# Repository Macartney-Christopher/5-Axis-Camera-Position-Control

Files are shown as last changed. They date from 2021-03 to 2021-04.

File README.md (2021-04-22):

# 5-Axis-Camera-Position-Control
  The "Tasmanian Devil" is a 5-axis camera position control system to get all the video shots you could dream of. The design is an extension of [isaac879](https://github.com/isaac879/Pan-Tilt-Mount)'s camera rig which allows the use of three axes, and shutter control. Using Isaac879's available pinouts and step files, their design was modified to account for focus and zoom, or dynamic lighting control.
  Go see the final product in action on YouTube [here](https://www.youtube.com/watch?v=kPsWlgf-iiQ)! 
  To understand the modifications made it is strongly suggested to look at [isaac879](https://github.com/isaac879/Pan-Tilt-Mount)'s original work on this project.

## Table of Contents
### 1. [Mechanical Design](Mechanical.md)
### 2. [Hardware Design](Hardware.md)
### 3. [Software Design](Software.md)

## Setup
1. Plug the power cable to an outlet
2. Plug the Xbox controller and the USB cable to your computer
3. Download the repository and extract the folder [Tasmanian_Launch](Tasmanian_Launch).
4. Update [serial_port.txt](Tasmanian_Launch/serial_port.txt) in the folder with the port that the Nano is connected to. Go to Device Manager>Ports to find the port number (ex: COM4).
5. Double-click on [Tasmanian_Launch.bat](Tasmanian_Launch/Tasmanian_Launch.bat)
6. Enjoy!

## Do It Yourself
### Build
1. Upload the Arduino code to the Nano 33 IoT
3. Assemble the 3D prints
4. Set up the wiring
5. Open the and compile the Bluetooth code on C++ compiler

#### With Gaming Controller
&nbsp;&nbsp;&nbsp;Follow the "Setup" protocol

#### Without Gaming Controller
1. Compile the Arduino code [here](FlashStorage_PanTiltMount/FlashStorage_PanTiltMount.ino) 
3. Ensure all cables are connected
4. Compile and execute
5. Operate in Arduino IDE using [these commands](FlashStorage_PanTiltMount/5-Axis_Position_Control_Commands.pdf)

## Credits
  The mechanical, hardware and software design is an adapted version of [isaac879](https://github.com/isaac879/Pan-Tilt-Mount)'s project. Isaac879 did a tremendous job with every aspect of the project and shows great skill in his other project as well. [Isaac879's video](https://www.youtube.com/watch?v=1FfB7cLkUyQ) is very well structured and edited.
## License
[Project license](LICENSE).

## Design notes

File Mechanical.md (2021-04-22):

# Mechanical


## Camera Mount Adaptability
  - Design 1: Extendable Camera Mount
    - Motive: Possibility that a camera will not fit
      - Allows a snug fit for any camera
      -	Reduces possibility for camera to rotate on center screw
      -	Required additional sliding mechanisms
      -	Involved too little rigidity in the system
  - Design 2: Freedom of Screw Position & Larger Mount
    - Motive: Not enough options for camera position
      -	Allows fit for all current and future DSLRs
      -	Allows for lateral and longitudinal positioning of camera
      -	Allows for optimal position of center of mass
      -	Possibility of camera rotation (mitigated by tightness 

    #### Design 2 outweighed Design 1
 

## Slider Mount Tightening
  - Design 1: Spring Loaded Wheel Shaft (4 wheels total)
    - Motive: Consistent Fitment to Rail 
      - Allows for simple setup
      - Requires strong springs in compression
      - Not mechanically reliable
  - Design 2: Eccentric Screw (3 wheels total)
    - Motive: More efficient design solution
      - Uses less wheels
      -	Allows for higher mechanical reliability
      -	Allows for desired tightness using tools
      -	3D printable

    #### Design 2 outweighed Design 1
    

## Additional Stepper Motors - Focus & Zoom Control
  - Design 1: Motors attached on the camera mount and adjustable
    - Motive: Fixed on the path of the camera
      -	Allows adjustability of both axes (focus & zoom)
      -	Proximity to lens
      -	Collides with the board and wiring in all optimal camera shots
  - Design 2: Motors attached to the external flash unit of the camera
    - Motive: Fixed on the path of the camera
      -	Allows adjustability of both axes (focus & zoom)
      -	Proximity to lens
      -	Only collides with board if camera is upside-down (unlikely)
      -	Gravity helps prevent any skipping of the gears because they are above the lens

	  #### Design 2 outweighed Design 1
	  

## Dynamic Lighting
&nbsp;&nbsp;&nbsp;To control the lights alongside the entire "Tasmanian Devil" the design must be compatible with the current light and tripod design. The following design allows for the rig to be easily set on the tripod and controlled from a distance.



## 3D Printing Material
&nbsp;&nbsp;&nbsp;The entire 5-axis camera rig is made of PLA, a relatively strong plastic and easy to work with. Two axes work with gears to increase ratio and precision. The contact from the gears could lead to increased vibrations and inconsistent filming. When printing one of the gears twice, once in semi-flexible and another flexible, there was no significant change to the recording. Moreover, softer teeth could increase the chances of gears skipping which would create shaking in the video at higher speeds. Gears as shown below:<br/>


## Assembling In SolidWorks
### Assembly
&nbsp;&nbsp;&nbsp;When assembling mechanical parts it is to your advantage to include screws, nuts, and other typically ignored components. All CAD files the nuts, screws, and bearings can be found on McMaster-Carr's website with many options for thread, pitch, head, etc. Ignoring to include the screws can lead to possible collisions with parts or even worse, a camera.
For a project like this, it may be advantageous to have a second assembly in which you can include the components to be printed. Often, when printing, offsets and chamfers are required depending on the printer's quality. A second assembly helps visualize the offsets and where you might be missing some.

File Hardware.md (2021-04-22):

# Hardware

&nbsp;&nbsp;&nbsp;The final objective for the camera is to control it via Bluetooth with the given code using the custom PCB. Keep in mind that this report is from a maker who didn't know what a stepper motor was before starting the project.

## CNC Shield: Driving Steppers Directly

&nbsp;&nbsp;&nbsp;With the mechanical parts fully assembled, the camera system needed to be tested. Driving the steppers directly using a CNC Shield through Arduino mitigates any issues that could arise from code and wiring. [Find code here](Iteration2-Code/CNC_Shield_Direct_Drive.ino) .

## CNC Shield: Driving Steppers with Universal G-Code Sender (UGS)
Use Universal G-Code Sender with the CNC Shield to rapidly and realistically simulate the controls of the steppers. 
1. Upload Grbl source code to the Arduino Uno [here on Github](https://github.com/grbl/grbl/blob/master/grbl/examples/grblUpload/grblUpload.ino).
2. Download Universal G-Code Sender and connect your Arduino Uno.
3. Setup stepper motors and drivers to CNC shield.
4. Press connect on the top corner and ensure the Arduino Uno is connected.
5. You're done!
 
#### Problem 
&nbsp;&nbsp;&nbsp;Using UGS for the camera position control is not ideal because entering the G commands manually is tedious. The issue is that the three core motors don't move the body in cartesian axes. Two motors rotate the body around its center and one moves along the x-axis. Moreover, the two motors also have a gear ratio which don't represent the rotation of the body 1:1 with the motors. 

#### Solution
1. Draw what the motors would do in cartesian coordinates and convert to G commands.
	This is an interesting idea because the user could visually see the sequence of motor actuation. The biggest issue is being able to constantly convert to cartesian coordinates as the user draws on two of three axes. 
2. Write code to enter the desired angles of the camera and output the G commands.
	This idea is feasible and both ends of the black box make sense for the user. [See C# code here](Iteration2-Code/GCode_Maker.cs).

&nbsp;&nbsp;&nbsp;The C# program asks for the angle of tilting and panning, and the distance of slider travel. It gives in return two G commands, the first to set the initial position and the second to execute the desired move.
[Watch an example video on Youtube](https://youtu.be/lNg3zl9IBe4).

## Stepper Motor Driver Setup
&nbsp;&nbsp;&nbsp;When installing new drivers on the board make sure that the current limiting is set correctly using the potentiometer. For reference, Current Limit = VRef x 2.
Example: The A4988 stepper driver has a current limit of 2 A, which realistically is a bit less unless the cooling on the IC (integrated circuit) is 100% efficient. Based on the above equation that means the VRef is approximately 0.9 A. To ensure your chip doesn't burn out it is highly suggested to slightly reduce your VRef and add a heat sink to the driver. 
To test if your driver won't burn out turn on your system with your finger on the heat sink, if it gets too hot then immediately turn off your system and troubleshoot.
- Ensure that a motor is connected to draw power
- Double check your current limit and the VRef on the potentiometer
- Test your driver on a working system to check its functionality

## Troubleshoot: Why is my stepper motor not working?

- Is the motor is connected?
- Is the power cable connected and turned on?
- Is the motor receiving enough power? Check with a multimeter
- Is the header for the motor receiving data from the board? Check connections with a multimeter
- Is the motor broken? Plug it into a working system to check its functionality

## Using a Custom PCB
&nbsp;&nbsp;&nbsp;Isaac879 includes the files and the component list to build the PCB in his repository. After soldering the components to the board we can begin testing.
*Note: The final objective is to have five total stepper motors, two more than what the PCB accounts for.*

##### Soldering
&nbsp;&nbsp;&nbsp;The only challenge is keeping the headers in the upright position while soldering on the opposite side. Additionally, this project upgrade counts 3x hall sensors wired to headers, 8x 7-10cm F-F wires, and 2x 7-10cm F-F split wires.

### Nano Compatibility
#### Using an Arduino Nano 
&nbsp;&nbsp;&nbsp;Isaac879 uses almost the entire static and dynamic memory available on an Arduino Nano to complete his project. The PCB worked when adding the Nano to the PCB and uploading isaac879's original code.

##### Problem
&nbsp;&nbsp;&nbsp;Initializing the two additional steppers with AccelStepper quickly takes up memory in the Nano. The code takes up 107% capacity only with initialization. Removing functions that are not critical, such as all that operate the camera shutter, is still not enough. An alternative board is necessary.

##### Solution
&nbsp;&nbsp;&nbsp;The Arduino Nano 33 BLE solves the memory issue. Moreover, the board has CPU Flash Memory which replaces the EEPROM.

#### Using an Arduino Nano 33 BLE
&nbsp;&nbsp;&nbsp;With the Arduino Nano 33 BLE there's plenty of memory to initialize all five stepper motors. The integrated Bluetooth on the Nano 33 BLE makes the Bluetooth header on the PCB available.

##### Problem
&nbsp;&nbsp;&nbsp; An architecture error comes up when changing the EEPROM to FlashStorage:

The architecture of the CPU is not compatible with the FlashStorage library. The workarounds with the same board are complex and require extensive knowledge of CPU architecture.

##### Solution
&nbsp;&nbsp;&nbsp;Finally, the Arduino Nano 33 IoT doesn't present any compilation issues and worked great.

#### Using an Arduino Nano 33 IoT
&nbsp;&nbsp;&nbsp;With the Arduino Nano 33 IoT, everything compiles perfectly. There's enough memory and the correct architecture for the FlashStorage library.

### Finding PCB Pinouts
&nbsp;&nbsp;&nbsp;Adding two more steppers is critical for the project. There are eight free pins on the PCB that can be used for digital signals: D0 (RX), D1 (TX), D2, D13, A1, A2, A6, and A7. Pins 0 and 1, and pin 2 on H1 belong to the camera trigger and a hall sensor respectively. The camera trigger is not necessary for this project, the fourth hall sensor does not add value to this project.
Thankfully the 28BYJ-48 stepper motors and their respective ULN2003 drivers only require four digital pins. The eight pins are perfect for the two small stepper motors.

### Modifying the PCB
&nbsp;&nbsp;&nbsp;*Note: To implement the two additional steppers the camera shutter trigger function must be sacrificed to use its digital pinout.*<br/>
&nbsp;&nbsp;&nbsp;***Suggestion: To not lose the camera trigger function and make the setup cleaner it is suggested to improve on the PCB design and simply order it with the correct modifications as explained below.***

&nbsp;&nbsp;&nbsp;To begin, R1 and R5 must be shorted because their corresponding pins D0 (RX) and A1 pins are not being used for what the PCB intended. Ensure that the resistor is not part of the circuit at all or it will affect the digital signal to the stepper motor. 
Next, cut the PCB at the designated lines to not short out the Nano 33 IoT.



The Nano does not relay the power to the hall sensor due to the cuts therefore let us override that as shown using the shorter yellow cable in the image below.



&nbsp;&nbsp;&nbsp;To implement the additional stepper motors male headers are required on the free pinouts to connect the ULN2003 drivers. For pin A2 there is no free pinout on the PCB but soldering a wire with a female end straight underneath the Nano header works just as well as shown with the white wire in the image above. <br/> 
 
&nbsp;&nbsp;&nbsp;Finally, connect the 7-10cm wires from the digital pinouts to the ULN2003 drivers and the two split wires from the PCB ground and power to the two drivers. The wiring should look like the below.



## Connecting a Gaming Controller
&nbsp;&nbsp;&nbsp;The use of a gaming controller to control the system is a great addition. Issac879 uses an Xbox controller although there didn't seem to be an issue with using any other standard remote.
### Problem
&nbsp;&nbsp;&nbsp;After some attempts, the serial port would not recognize any remote, whether it was USB or Bluetooth. All controllers used to use DirectInput to communicate games and programs. Windows then created XInput so only Xbox controllers could be used with Xbox. 
&nbsp;&nbsp;&nbsp;Isaac879 uses XInput to connect the Xbox controller to the camera system which meant that the serial port issue was due to the controller not being Xbox. Either the code or the controller had to be changed. 

### Solution
#### Solution 1: 
&nbsp;&nbsp;&nbsp;By using an application called MogaSerial, the Moga Pro 2 on-hand acted as an XInput controller. It worked great for a couple of days. Unfortunately, in February 2021, MogaSerial is still inconsistent and does not always connect to the Moga Pro 2. Despite the program not being supported by Windows, the maker [Zel-oz](https://github.com/Zel-os/MogaSerial) is still improving it.
#### Solution 2: 
&nbsp;&nbsp;&nbsp;Modifying the code to use DirectInput is the ideal solution but it is a complex task for any individual unfamiliar with this old Microsoft API.
#### Solution 3:
&nbsp;&nbsp;&nbsp;For reliability and timing it is better to purchase an Xbox controller if any of the previous solutions don't work but try them!

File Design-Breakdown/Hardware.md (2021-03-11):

# Hardware

&nbsp;&nbsp;&nbsp;The final objective for the Camera is to control it via Bluetooth with the given code using the custom PCB. Keep in mind that this report is from a maker who didn't know what a stepper motor was before starting the project.

## CNC Shield: Driving Steppers Directly

&nbsp;&nbsp;&nbsp;With the mechanical parts fully assembled, the camera system needed to be tested. Driving the steppers directly using a CNC Shield through Arduino mitigates any issues that could arise from code and wiring. [Find code here](Iteration-Code/CNC_Shield_Direct_Drive.ino) .

## CNC Shield: Driving Steppers with Universal G-Code Sender (UGS)
Use Universal G-Code Sender with the CNC Shield to rapidly and realistically simulate the controls of the steppers. 
1. Upload Grbl source code to the Arduino Uno [here on Github](https://github.com/grbl/grbl/blob/master/grbl/examples/grblUpload/grblUpload.ino).
2. Download Universal G-Code Sender and connect your Arduino Uno.
3. Setup stepper motors and drivers to CNC shield.
4. Press connect on the top corner and ensure the Arduino Uno is connected.
5. You're done!
 
#### Problem 
&nbsp;&nbsp;&nbsp;Using UGS for the camera position control is not ideal because entering the G commands manually is tedious. The issue is that the three core motors don't move the body in cartesian axes. Two motors rotate the body around its center and one moves along the x axis. Moreover, the two motors also have a gear ratios which don't represent the rotation of the body 1:1 with the motors. 

#### Solution
1. Draw what the motors would do in cartesian coordinates and convert to G commands.
	This is an interesting idea because the user could visually see the sequence of motor actuation. The biggest issue is being able to constantly convert to cartesian coordinates as the user draws on two of three axes. 
2. Write code to enter the desired angles of the camera and output the G commands.
	This idea is feasible and both ends of the blackbox make sense for the user. [See C# code here](Iteration-Code/GCode_Maker.cs).

&nbsp;&nbsp;&nbsp;The C# program asks for angle of tilting and panning, and the distance of slider travel. It gives in return two G commands, the first to set the initial position and the second to execute the desired move.
[Watch an example video on Youtube](https://youtu.be/lNg3zl9IBe4).

## Using a Custom PCB
&nbsp;&nbsp;&nbsp;Isaac879 includes the files and the component list to build the PCB in his repository. After soldering the components to the board we can begin testing.
*Note: The final objective is to have five total stepper motors, two more than what the PCB accounts for.*

##### Soldering
&nbsp;&nbsp;&nbsp;The only challenge wben soldering is keeping the headers in the upright position while soldering on the opposite side. Additionally, this project upgrade counts 3x hall sensors wired to headers, 8x 7-10cm F-F wires, and 2x 7-10cm F-F split wires.

### Nano Compatibility
#### Using an Arduino Nano 
&nbsp;&nbsp;&nbsp;Isaac879 uses almost the entire static and dynamic memory available on an Arduino Nano to complete his project. The PCB worked when adding the Nano to the PCB and uploading isaac879's original code.

##### Problem
&nbsp;&nbsp;&nbsp;Initializing the two additional steppers with AccelStepper quickly take up memory in the Nano. The code takes up 107% capacity only with initilization. Removing functions that are not critical, such as all that operate the camera shutter, is still not enough. An alternative board is necessary.

##### Solution
&nbsp;&nbsp;&nbsp;The Arduino Nano 33 BLE solves the memory issue. Moreover, the board has CPU Flash Memory which replaces the EEPROM.

#### Using an Arduino Nano 33 BLE
&nbsp;&nbsp;&nbsp;With the Arduino Nano 33 BLE there's plenty of memory to initialize all five stepper motors. The integrated bluetooth on the Nano 33 BLE makes the Bluetooth header on the PCB available.

##### Problem
&nbsp;&nbsp;&nbsp; An architecture error comes up when changing the EEPROM to FlashStorage:

The architecture of the CPU is not compatible with FlashStorage library. The workarounds with the same board are complex and require extensive knowledge of CPU architecture.

##### Solution
&nbsp;&nbsp;&nbsp;Finally, the Arduino Nano 33 IoT doesn't present any compilation issues and worked great.

#### Using an Arduino Nano 33 IoT
&nbsp;&nbsp;&nbsp;With the Arduino Nano 33 IoT everything compiles perfectly. There's enough memory and the correct architecture for the FlashStorage library.

### Finding PCB Pinouts
&nbsp;&nbsp;&nbsp;Adding two more steppers is critical for the project. There are eight free pins on the PCB that can be used for digital signals: D0 (RX), D1 (TX), D2, D13, A1, A2, A6, and A7. Pins 0 and 1, and pin 2 on H1 belong to the camera trigger and a hall sensor respectively. The camera trigger is not necessary for this project, the fourth hall sensor does not add value to this project.
Thankfully the 28BYJ-48 stepper motors and their respective ULN2003 drivers only require four digital pins. The eight pins are perfect for the two small stepper motors.

### Modifying the PCB
&nbsp;&nbsp;&nbsp;*Note: To implement the two additional steppers the camera shutter trigger function must be sacrificed to use its digital pinout.*
&nbsp;&nbsp;&nbsp;***Suggestion: To not lose the camera trigger function and make the setup cleaner it is suggested to improve on the PCB design and simply order it with the correct modifications as explained below.***

&nbsp;&nbsp;&nbsp;The first step to implement the additional stepper motors is to solder male headers on the free pinouts to connect the ULN2003 drivers. For pin A2 there is no free pinout on the pCB but soldering a wire with a female end straight underneath the Nano header works just as well. 
Secondly, R1 and R5 must be shorted because their corresponding pins D0 (RX) and A1 pins are not being used for what the PCB intended. Ensure that the resistance is not part of the circuit at all or it will affect the digital signal to the stepper motor.

Wire from Nano Vin to H3 power
Wire from Nano 3.3V to P2 5V
Cutting 5V supply from H1 through the P1 because the nano 33 iot can only output 3.3V. Short 5V supply  to H1
Finally, connect the 7-10cm wires from the digital pinouts to the ULN2003 drivers and the two split wires from the PCB ground and power to the two drivers. The wiring should look like the below.

## Connecting a Gaming Controller
&nbsp;&nbsp;&nbsp;The use of a gaming controller to control the system is a great addition. Issac879 uses an Xbox controller although there didn't seem to be an issue with using any other standard remote.
### Problem
&nbsp;&nbsp;&nbsp;After some attemps the serial port would not recognize any remote, whether it was USB or Bluetooth. All controllers used to use DirectInput to communicate games and programs. Windows then created XInput for so only Xbox controllers could be used with Xbox. 
&nbsp;&nbsp;&nbsp;Isaac879 uses XInput to connect the Xbox controller to the camera system which meant that the serial port issue was due to the controller not being Xbox. Either the code or the controller had to be changed. 

### Solution
#### Solution 1: 
&nbsp;&nbsp;&nbsp;By using an application called MogaSerial, the Moga Pro 2 on-hand acted as an XInput controller. It worked great for a couple days. Unfortunately, in February 2021, MogaSerial is still inconsistent and does not always connect to the Moga Pro 2. Despite the program not being supported by Windows, the maker [Zel-oz](https://github.com/Zel-os/MogaSerial) is still improving it.
#### Solution 2: 
&nbsp;&nbsp;&nbsp;Modifying the code to use DirectInput is the ideal solution but it is a complex task for any individual unfamiliar with this old Microsoft API.
#### Solution 3:
&nbsp;&nbsp;&nbsp;For reliability and timing it is better to purchase an Xbox controller if any of the previous solutions don't work but try them!

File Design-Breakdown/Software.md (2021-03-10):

# Software

## Getting Familiar
&nbsp;&nbsp;&nbsp;In total there are over 2000 lines of code. The best way to approach it is to get familiar with each library and then the functions in the code.
The AccelStepper and MultiStepper libraries are complimentary, often one used together. [Isaac879](https://github.com/isaac879/Pan-Tilt-Mount) uses EEPROM to store values while the system is off.

## Obstacles
### EEPROM & FlashStorage
&nbsp;&nbsp;&nbsp;When changing from the Nano to the Nano 33 BLE and the Nano 33 IoT there's a complete loss of EEPROM. That issue was mitigated by including the FlashStorage library.
FlashStorage is more reliable than EEPROM. If the Nano was reset then none of the functions would function because the EEPROM values were uninitialized. With the Nano 33 IoT and FlashStorage there is still functionality even when reset.

### Adding 2 Stepper Motors
&nbsp;&nbsp;&nbsp;When initializing the 2 additional motors in the code using AccelStepper ensure the other functions are not affected. Each function is modified by increasing data arrays, modifying function inputs/outputs, and adding functions and variables.

&nbsp;&nbsp;&nbsp;It's simple to implement the functions and variables because they follow the same structure as the native code. Ensuring the initial values are correct for the system's parameters requires a lot of empirical testing based on visual results of the motor actuation.

&nbsp;&nbsp;&nbsp;Increasing the arrays and the function inputs can cause other issues in the call sequence. Three motors have a home (neutral) position based on hall effect sensors although the two additional motors do not. When adding the motors to ```findHome()``` they weren't included with the hall sensing section or else the two additional motors would continuously rotate attempting to find a home position.

### Driving CPU Port Directly
&nbsp;&nbsp;&nbsp;[Isaac879](https://github.com/isaac879/Pan-Tilt-Mount)'s implements a function that drives the microcontroller directly to set the step mode on their TMC2208 drivers.

##### Arduino Nano Microcontroller Ports

&nbsp;&nbsp;&nbsp;As shown below, PORTB is used yet undeclared in the entire code. Moreover, no results come up when searching for PORTB.

```c++
if(newMode == HALF_STEP){
        PORTB |=   B00001000; //MS1 high
        PORTB &= ~(B00000100); //MS2 low 
    }
    else if(newMode == QUARTER_STEP){
        PORTB |=   B00000100; //MS2 high
        PORTB &= ~(B00001000); //MS1 low
    }
    else if(newMode == EIGHTH_STEP){
        PORTB &= ~(B00001100); //MS1 and MS2 low
    }
    else if(newMode == SIXTEENTH_STEP){
        PORTB |= B00001100; //MS1 and MS2 high
    }
```
&nbsp;&nbsp;&nbsp;Here, isaac879 uses the microcontroller ports directly. As seen above, there are eight B Ports which correspond to the 8 digits in the code. Despite how efficient it is for the regular Nano, the Nano 33 IoT is faster and the code could be simplified using digitalWrite().

### Bit Manipulation - Bluetooth Implementation
&nbsp;&nbsp;&nbsp;Sending the commands from the controller involves sending a character array. The information is allocated in the array like the following:
```c++
int sendSliderPanTiltStepSpeed(int command, short* arr) {
	char data[11]; //Data array to send

	data[0] = command;
	data[1] = (arr[0] >> 8) & 0xFF; //Gets the most significant byte
	data[2] = arr[0] & 0xFF; //Gets the second most significant byte
	data[3] = (arr[1] >> 8) & 0xFF;
	....
	data[9] = (arr[4] >> 8) & 0xFF;
	data[10] = arr[4] & 0xFF; //Gets the least significant byte

	serialWrite(data, sizeof(data)); //Send the command and the 10 bytes of data
```
&nbsp;&nbsp;&nbsp;On the receiving end, in Arduino, the native code takes in the information by shifting 8 bits at a time:
```c++
    int sliderStepSpeed = (Serial.read() << 8) + Serial.read(); 
    int panStepSpeed = (Serial.read() << 8) + Serial.read(); 
    ...
    int zoomStepSpeed = (Serial.read() << 8) + Serial.read();
```       
&nbsp;&nbsp;&nbsp;The data was not receiving properly with the Nano 33 IoT. After further testing, all the ```int```'s had to be changed to ```int16_t```'s to explicitly convert it to a 16 bit integer. That would be due to the Nano 33 IoT being configured slightly differently than the Nano.

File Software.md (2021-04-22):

# Software

## Getting Familiar
&nbsp;&nbsp;&nbsp;In total there are over 2500 lines of code. The best way to approach it is to get familiar with each library and then the functions in the code.
The AccelStepper and MultiStepper libraries are complimentary, often used together. [Isaac879](https://github.com/isaac879/Pan-Tilt-Mount) uses EEPROM to store values while the system is off.

## Obstacles
### EEPROM & FlashStorage
&nbsp;&nbsp;&nbsp;When changing from the Nano to the Nano 33 BLE and the Nano 33 IoT there's a complete loss of EEPROM. That issue was mitigated by including the FlashStorage library.
FlashStorage is more reliable than EEPROM. If the Nano was reset then none of the functions would function because the EEPROM values were uninitialized. With the Nano 33 IoT and FlashStorage, there is still functionality even when reset.

### Adding 2 Stepper Motors
&nbsp;&nbsp;&nbsp;When initializing the 2 additional motors in the code using AccelStepper, ensure the other functions are not affected. Each function is modified by increasing data arrays, increasing function inputs/outputs, and adding functions and variables to integrate the extra motors.

&nbsp;&nbsp;&nbsp;It's simple to implement the functions and variables because they follow the same structure as the native code. Ensuring the initial values are correct for the system's parameters requires empirical testing based on visual results.

&nbsp;&nbsp;&nbsp;Increasing the arrays and the function inputs can cause other issues in the call sequence. Three motors have a home (neutral) position based on hall effect sensors although the two additional motors do not. When adding the motors to ```findHome()``` they weren't included with the hall sensing section because hall sensors were not added alongside the two motors.

### Driving CPU Port Directly
&nbsp;&nbsp;&nbsp;[Isaac879](https://github.com/isaac879/Pan-Tilt-Mount)'s implements a function that interacts the microcontroller ports directly to set the step mode on their TMC2208 drivers. For example, to set the step mode to 1/16:
```c++
if(newMode == SIXTEENTH_STEP){
        PORTB |= B00001100; //MS1 and MS2 high
}
```
&nbsp;&nbsp;&nbsp;The above indicates to set the 3rd and 4th B ports to HIGH and keeping all others LOW. The reason for this syntax is efficiency, it sets the MS1 and MS2 pins to high directly instead of going through a complementary function. For a maker it's easier to understand the following:
```c++
if(newMode == SIXTEENTH_STEP){
	digitalWrite(PIN_MS1, HIGH);
	digitalWrite(PIN_MS2, HIGH);
}
```
&nbsp;&nbsp;&nbsp;For a comprehensive look at this, here are the pinouts of the CPU on the Nano:



&nbsp;&nbsp;&nbsp;As seen above, there are eight B Ports that correspond to the 8 digits in the code. Despite how efficient it is for the regular Nano, the Nano 33 IoT is faster and the code could be simplified using digitalWrite().

### Bit Manipulation - Bluetooth Implementation
&nbsp;&nbsp;&nbsp;Sending the commands from the controller involves sending a character array. The information is allocated in the array as such:
```c++
int sendSliderPanTiltStepSpeed(int command, short* arr) {
	char data[11]; //Data array to send

	data[0] = command;
	data[1] = (arr[0] >> 8) & 0xFF; //Gets the most significant byte
	data[2] = arr[0] & 0xFF; //Gets the second most significant byte
	data[3] = (arr[1] >> 8) & 0xFF;
	....
	data[9] = (arr[4] >> 8) & 0xFF;
	data[10] = arr[4] & 0xFF; //Gets the least significant byte

	serialWrite(data, sizeof(data)); //Send the command and the 10 bytes of data
```
&nbsp;&nbsp;&nbsp;On the receiving end, in Arduino, the native code takes in the information by shifting 8 bits at a time:
```c++
    int sliderStepSpeed = (Serial.read() << 8) + Serial.read(); 
    int panStepSpeed = (Serial.read() << 8) + Serial.read(); 
    ...
    int zoomStepSpeed = (Serial.read() << 8) + Serial.read();
```       
&nbsp;&nbsp;&nbsp;The data was not receiving properly with the Nano 33 IoT. After further testing, all the ```int```'s had to be changed to ```int16_t```'s to explicitly convert it to a 16 bit integer. That is due to the Nano 33 IoT being configured slightly differently than the Nano.

### Adding Multi-Button Functions
&nbsp;&nbsp;&nbsp;Isaac879 can get the state of the Xbox Controller buttons using, for example:
```c++
if ((lastwButtons & UP_BUTTON) < (state.Gamepad.wButtons & UP_BUTTON))
```
&nbsp;&nbsp;&nbsp;The above simply checks if the last button pressed corresponds to the Up button on the D-Pad.
&nbsp;&nbsp;&nbsp;To add a multi-button function there needs to be a toggle button that allows the user to use other buttons for different actions.
Let us set the Y Button as the toggle button. When pressed we can switch a bool value:
```c++
if ((lastwButtons & Y_BUTTON) < (state.Gamepad.wButtons & Y_BUTTON)) { //if Y Button is pressed
	toggleButton = true;  					       //turn on the toggle feature
}
```
Now, when the Up Button is pressed there is one of two functions that gets called depending on the value of ```toggleButton```.
```c++
if ((lastwButtons & UP_BUTTON) < (state.Gamepad.wButtons & UP_BUTTON) && !toggleButton) { //when Y is NOT pressed the Up Button calls this function
...
}

if ((lastwButtons & UP_BUTTON) < (state.Gamepad.wButtons & UP_BUTTON) && toggleButton){ //when Y is pressed the Up Button calls this function
...
}
```
## Batch Files - Ease of use
&nbsp;&nbsp;&nbsp;Any user of the camera rig should be able to click on a few buttons to have the system ready without going into code. The solution to this is batch files:
For this project, the user only needs a connection from the gaming controller to the Arduino Nano 33 IoT and a document to explain the command functions.
From one batch file, there is no way to simultaneously run/open code and a pdf. One needs to be closed for the other to open. 
A simple workaround is to integrate two separate ```.bat``` files into a master batch file:
```bat
@ECHO OFF
start Xbox_Controller_Connection.bat 	rem Connects the Xbox controller to the Arduino Nano 33 IoT.
start Xbox_Controller_Commands.bat 	rem Shows Xbox controller commands to the user.
PAUSE
```

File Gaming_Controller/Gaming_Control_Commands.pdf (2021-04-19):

Function | Command
Sixteenth Step Mode (for smoother movement) | Click R stick
Save Position | A
Execute Moves | RB Button
Clear array | B
Edit current position | X
Report Status | Click L stick
Toggle Additional Function | Y Button
Increase Speed by 10% | Y + Up
Decrease Speed by 10% | Y + Down
Homing Setting 3 (all axes) | LB Button
Home | Start
First element | Up
Last element | Down
Step forwards in array | Right
Step backwards in array | Left
Step forwards in array | Right
Step backwards in array | Left

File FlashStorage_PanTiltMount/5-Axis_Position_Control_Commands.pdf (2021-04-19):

5-axis Camera Position Control System Functions

Setting parameters
Function | Command Character | Input Range
Report status | R | N/A
Set microstepping mode | m | 2, 4, 8, 16
Pan degrees | p | float
Tilt degrees | t | float
Slider millimeters | x | float
Focus degrees | f | float
Zoom degrees | y | float
Set pan speed (deg/s) | s | float
Set tilt speed (deg/s) | S | float
Set slider speed (mm/s) | X | float
Pan acceleration increment delay (µs) | q | 0 – 32676
Tilt acceleration increment delay (µs) | Q | 0 – 32676
Slider acceleration increment delay (µs) | w | 0 – 32676
Scale the speed of all keyframed movements | W | float
Invert pan direction | i | bool
Invert tilt direction | I | bool
Invert slider direction | j | bool
Invert focus direction | F | bool
Invert zoom direction | Y | bool
Enable stepper motors | e | N / A
Set pan degrees offset | o | float
Set tilt degrees offset | O | float
Set homing mode (0: no homing, 1: Slider, 2: Pan & Tilt, 3: All axes) | H | 0-3
Auto home all axes | A | N / A
Save settings to FlashStorage | U | N / A
Filming Functions
Function | Command Character | Input Range
Add keyframe position | # | N / A
Execute moves | ; | 1-32767
Move forward in keyframe array | > | N / A
Move backward in keyframe array | < | N / A
Jump to start of array | [ | N / A
Jump to end of array | ] | N / A
Edit current keyframe with current position | E | N / A
Add delay in keyframes (in ms) | d | 0 – 32676
Edit delay at current position | D | 0 - 32676
Clear all keyframe positions | C | N / A
Orbit point between 2 keyframes | @ | 0 – 32676
Calculate intercept of the first 2 keyframes | T | N / A

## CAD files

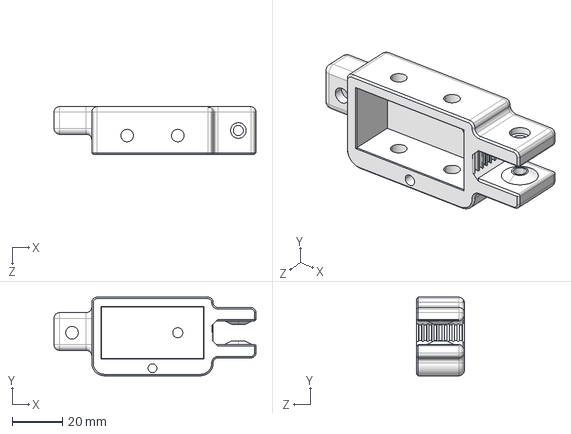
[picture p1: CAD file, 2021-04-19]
Step Files/2040 Rail Holder 2.STEP
80.2 x 31.2 x 19.0 mm

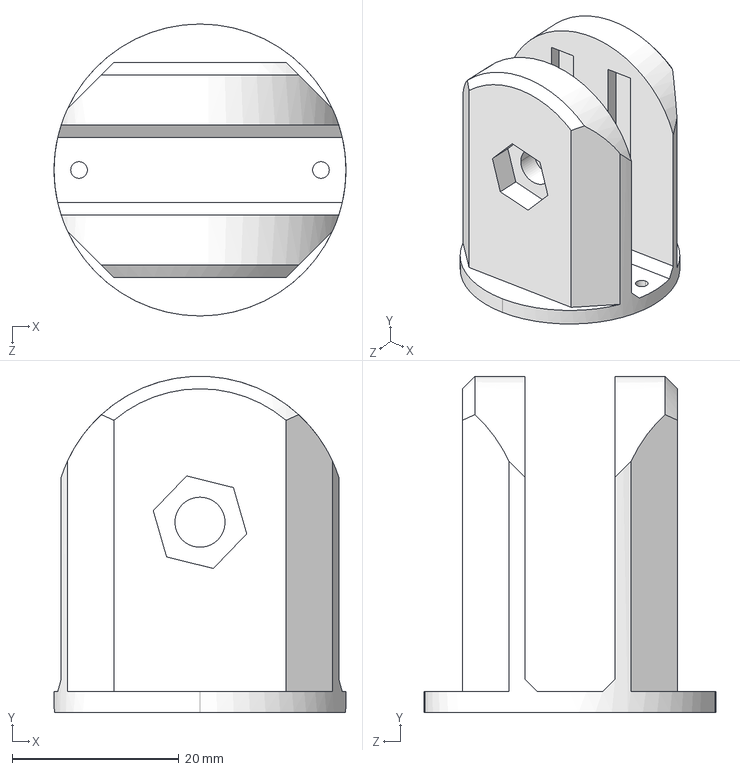
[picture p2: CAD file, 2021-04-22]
Step Files/Dynamic Lighting/Light Angle Adjuster2.STEP
35.0 x 40.3 x 35.0 mm

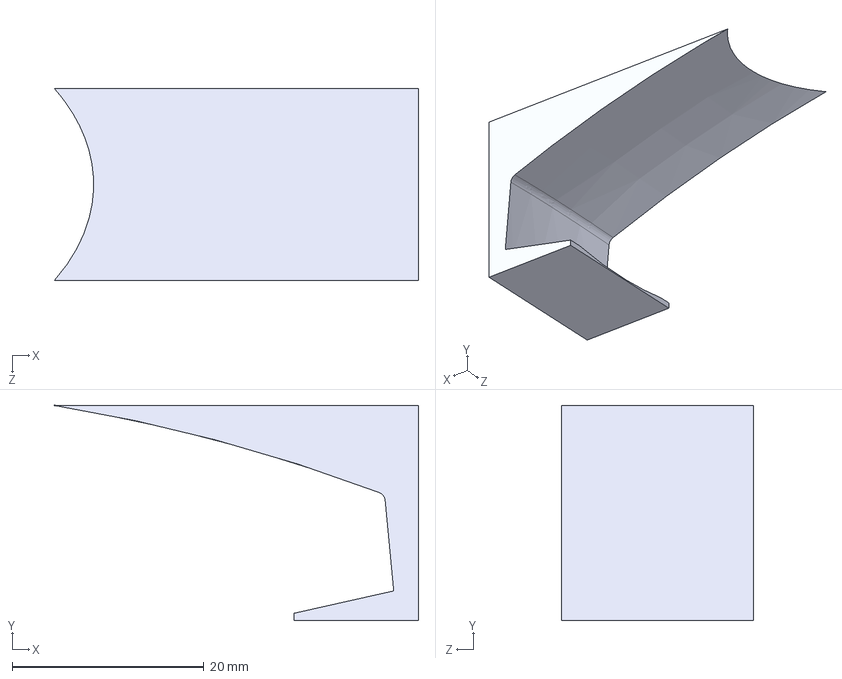
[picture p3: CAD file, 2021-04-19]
Step Files/Focus & Zoom Extension/Camera Mount.STEP
38.0 x 22.5 x 20.0 mm

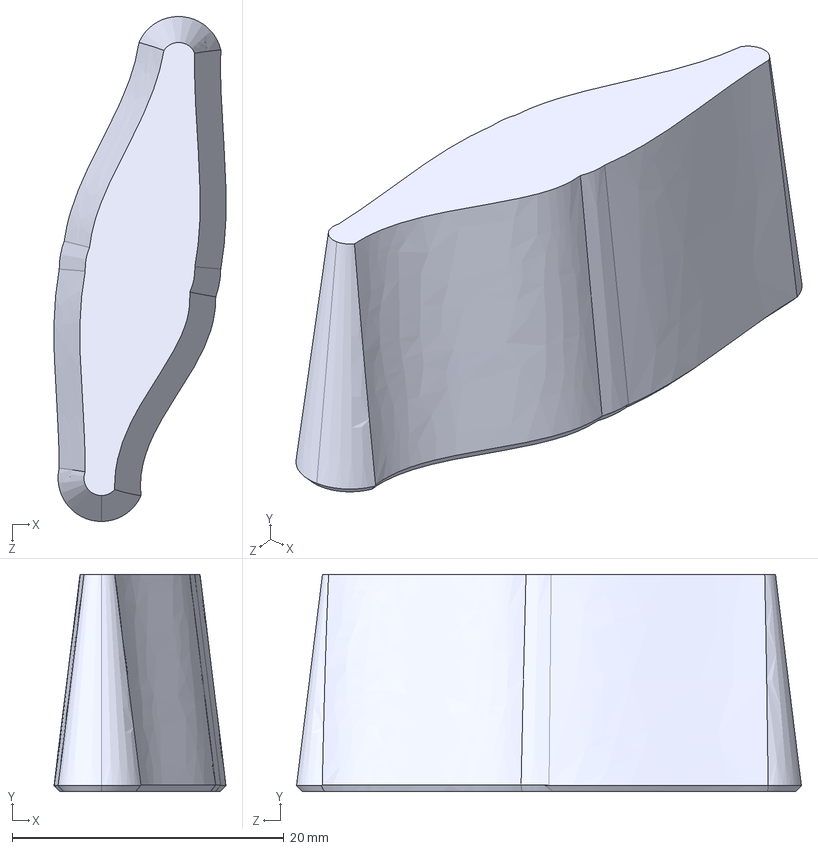
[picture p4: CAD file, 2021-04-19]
Step Files/Dynamic Lighting/Tightening Handle.STEP
12.6 x 16.0 x 37.2 mm

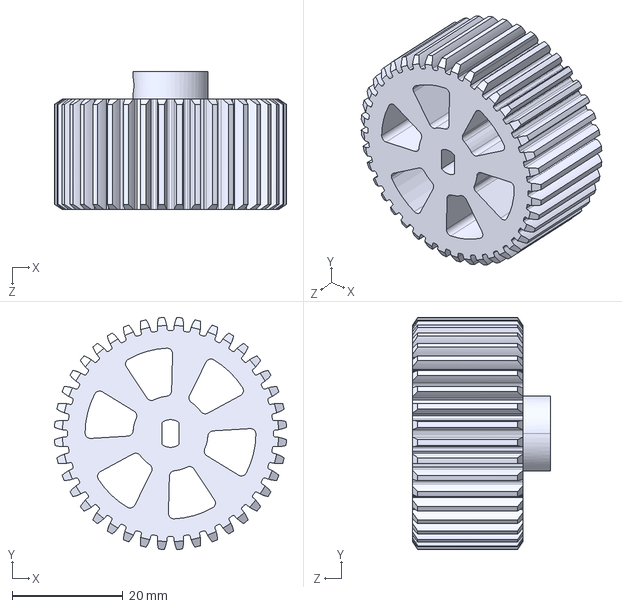
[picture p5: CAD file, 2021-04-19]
Step Files/Focus & Zoom Extension/Small Lens 40 tooth gear.STEP
41.9 x 41.9 x 25.0 mm

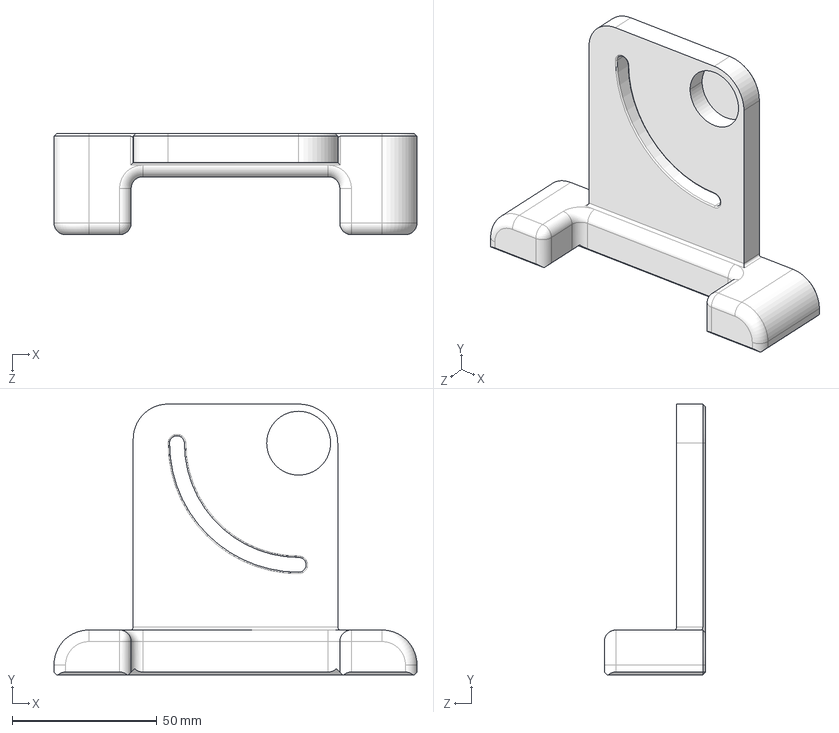
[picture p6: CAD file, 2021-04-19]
Step Files/2040 Angle Adjustment 1 .STEP
125.3 x 93.5 x 35.0 mm

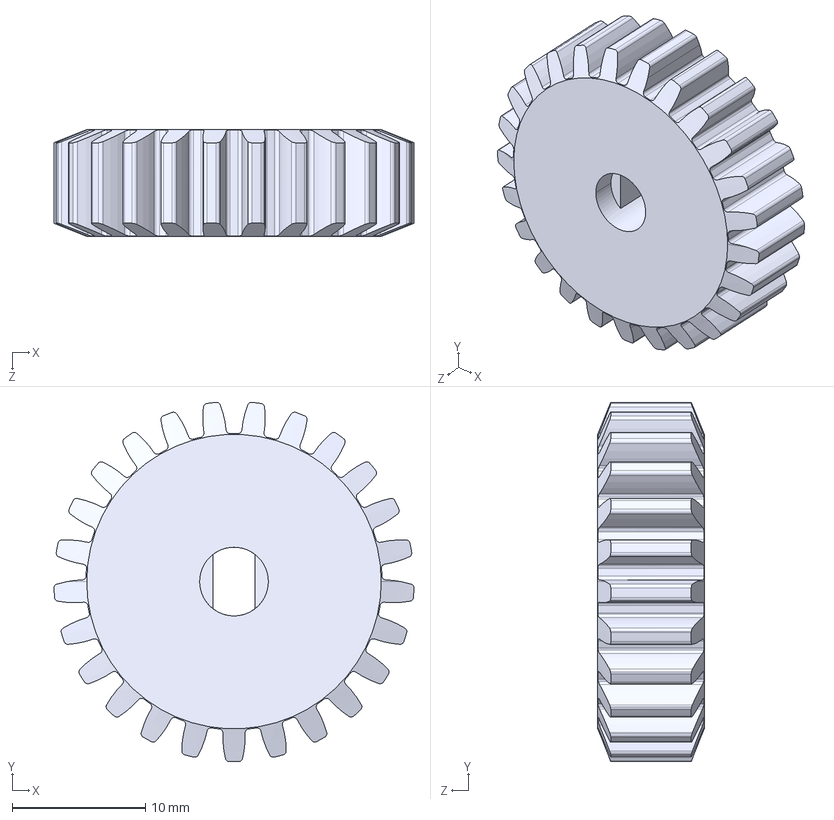
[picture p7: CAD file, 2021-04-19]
Step Files/Dynamic Lighting/Light Motor Gear.STEP
27.0 x 26.9 x 8.00 mm

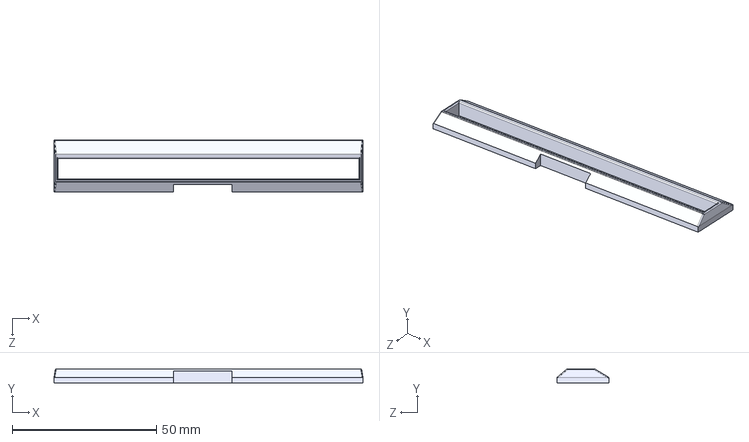
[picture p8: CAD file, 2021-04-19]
Step Files/Focus & Zoom Extension/Slot for Nuts.STEP
107.0 x 5.00 x 18.0 mm

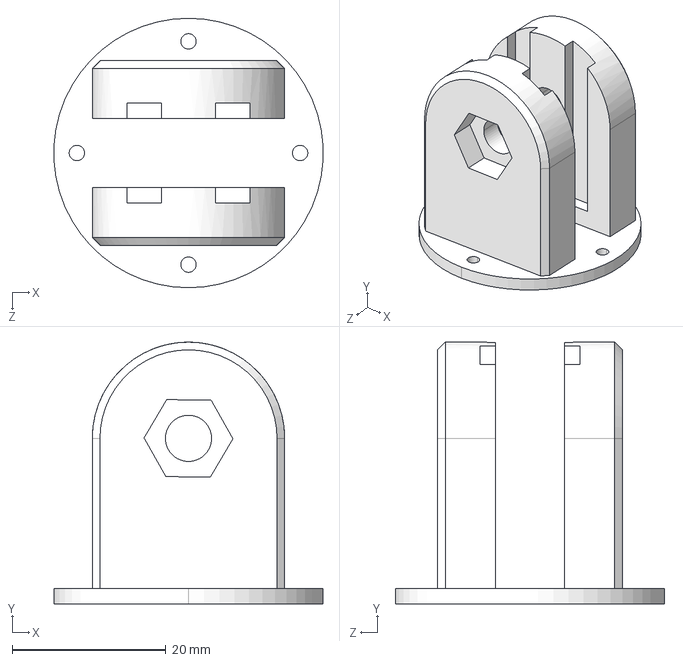
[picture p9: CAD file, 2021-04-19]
Step Files/Dynamic Lighting/Light Angle Adjuster.STEP
34.9 x 34.0 x 35.0 mm

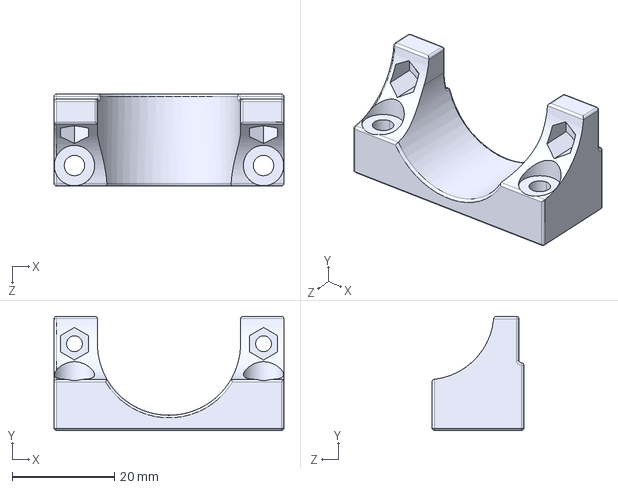
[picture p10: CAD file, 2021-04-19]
Step Files/Focus & Zoom Extension/28BYJ-48 Stepper Motor Mount.STEP
45.0 x 22.4 x 18.0 mm

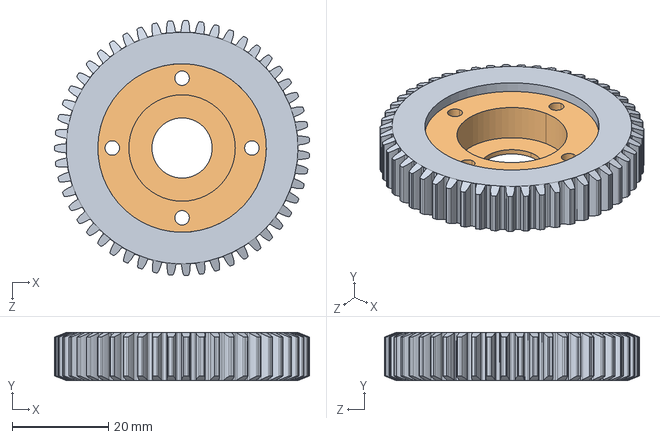
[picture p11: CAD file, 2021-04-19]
Step Files/Dynamic Lighting/Light Gear And Bearing Lower Mount.STEP
53.0 x 10.0 x 53.0 mm

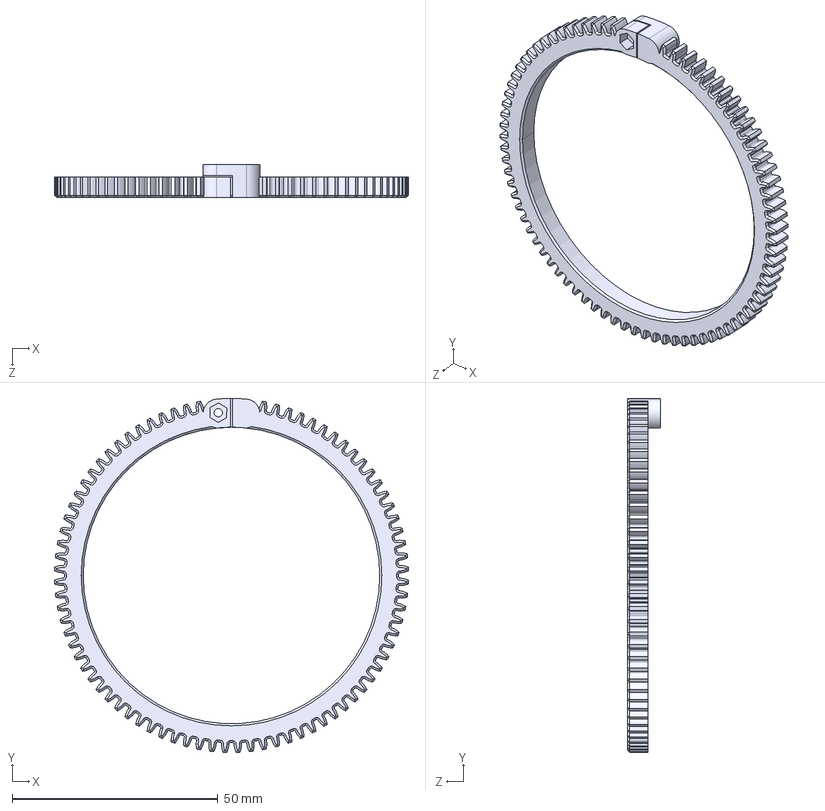
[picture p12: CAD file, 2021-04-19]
Step Files/Focus & Zoom Extension/Small Lens 84 tooth gear.STEP
86.0 x 86.0 x 8.00 mm

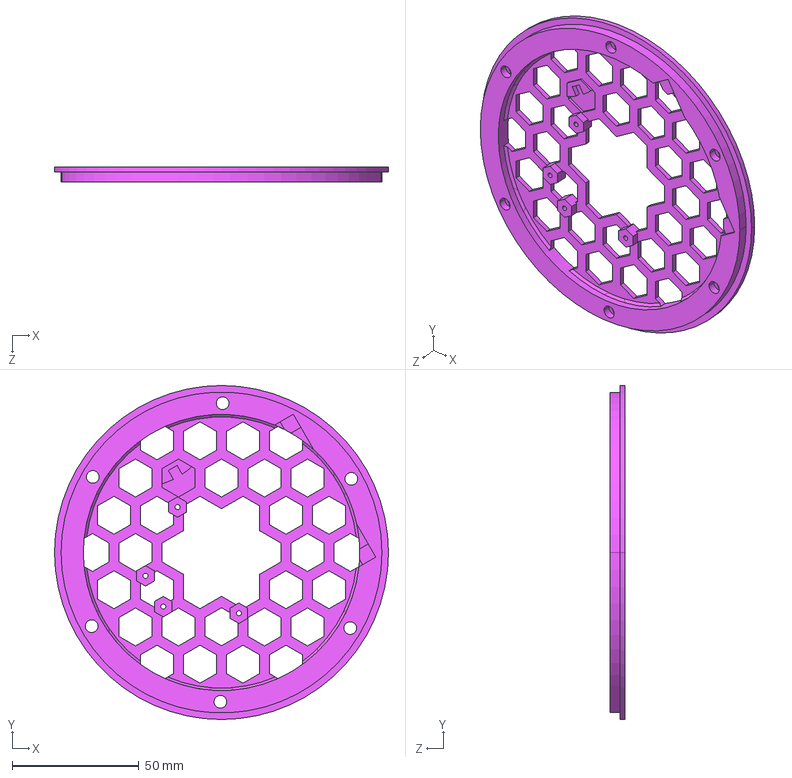
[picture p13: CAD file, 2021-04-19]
Step Files/Panning Hex Platform Clamp.STEP
132.0 x 132.0 x 6.00 mm

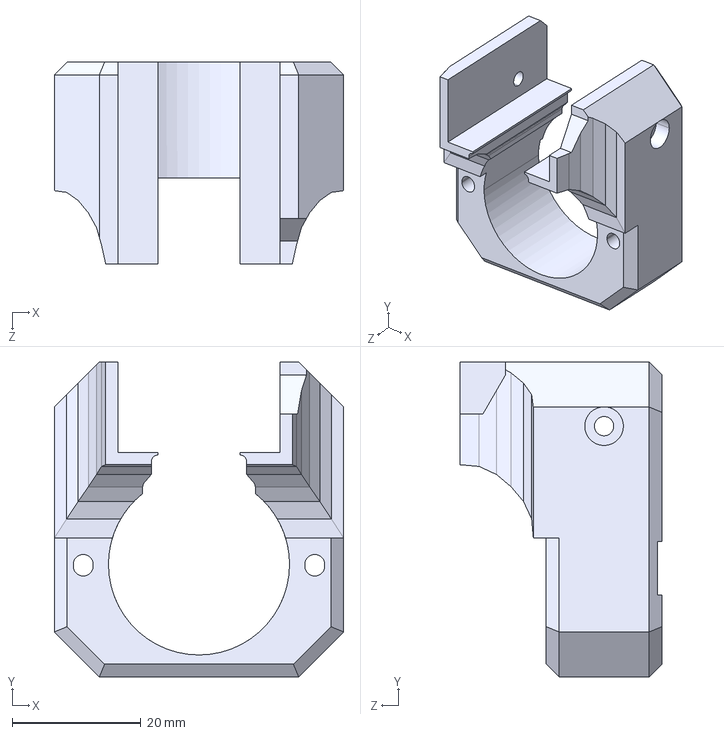
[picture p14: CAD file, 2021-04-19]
Step Files/Dynamic Lighting/Stepper Motor Mount.STEP
45.0 x 49.0 x 31.4 mm

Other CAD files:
Step Files/2040 Rail Holder 1.STEP
Step Files/2040 Angle Adjustment 2 .STEP
Step Files/Focus & Zoom Extension/Small Lens Double Motor Platform.STEP
Step Files/Tilt Hall Effect and Stepper Mount.STEP
Step Files/2040 Hall Effect Support.STEP
Step Files/2040 Slider bottom.STEP
Step Files/2040 Slider top.STEP
Step Files/Bearing Clip Ring.STEP
Step Files/Bearing Inner Race - 127 x 146.05 x 12.7mm.STEP
Step Files/Bearing Middle Cage - 127 x 146.05 x 12.7mm.STEP
Step Files/Bearing Outter Race - 127 x 146.05 x 12.7mm.STEP
Step Files/Belt Clamp Lever.STEP
Step Files/Camera Screw.STEP
Step Files/Dynamic Lighting/Tripod Mount.STEP
Step Files/Focus & Zoom Extension/Hot Shoe Cap.STEP
Step Files/Focus & Zoom Extension/Tilt Camera Mount.STEP
Step Files/Panning - 17 Tooth Herringbone Gear.STEP
Step Files/Panning Hall Sensor Mount.STEP
Step Files/Panning Platform.STEP
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

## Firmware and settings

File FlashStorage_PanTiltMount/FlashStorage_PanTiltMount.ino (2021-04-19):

/*--------------------------------------------------------------------------------------------------------------------------------------------------------
 * 
 * Pan Tilt Mount Focus Zoom STL files: https://www.thingiverse.com/thing:4547074
 * 
 * Isaac879's Project video: https://youtu.be/1FfB7cLkUyQ
 * 
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
 * Code written by isaac879-Christopher Macartney
 * 
 * Last modified: 03/09/2021
 *
 *--------------------------------------------------------------------------------------------------------------------------------------------------------*/


#include "panTiltMount.h"

/*--------------------------------------------------------------------------------------------------------------------------------------------------------*/

void setup(){
    initPanTilt();
}

void loop(){
    mainLoop();
}

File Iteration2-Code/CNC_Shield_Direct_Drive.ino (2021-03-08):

const int stepXPin = 2; //X.STEP
 const int dirXPin = 5; // X.DIR
 void setup() {
 // Sets the two pins as Outputs
 pinMode(stepXPin,OUTPUT); 
 pinMode(dirXPin,OUTPUT);
 }
 void loop() {
 digitalWrite(dirXPin,HIGH); // Enables the motor to move in a particular direction
 // Makes 200 pulses for making one full cycle rotation
 for(int x = 0; x < 1000; x++) {
 digitalWrite(stepXPin,HIGH); 
 delayMicroseconds(500); 
 digitalWrite(stepXPin,LOW); 
 delayMicroseconds(500); 
 }
 delay(1000); // One second delay
 
 digitalWrite(dirXPin,LOW); //Changes the rotations direction

 // Makes 400 pulses for making two full cycle rotation
 for(int x = 0; x < 400; x++) {
 digitalWrite(stepXPin,HIGH);
 delayMicroseconds(500);
 digitalWrite(stepXPin,LOW);
 delayMicroseconds(500);
 }
 delay(1000);
 }

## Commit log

2021-03-15 Rename 2040 Hall Effect Support.STEP to Step Files/2040 Hall Effect Support.STEP
    [2040 Hall Effect Support.STEP]
2021-03-15 Rename 2040 Rail Holder 1.STEP to Step Files/2040 Rail Holder 1.STEP
    [2040 Rail Holder 1.STEP]
2021-03-15 Rename 2040 Rail Holder 2.STEP to Step Files/2040 Rail Holder 2.STEP
    [2040 Rail Holder 2.STEP]
2021-03-15 Rename 2040 Slider bottom.STEP to Step Files/2040 Slider bottom.STEP
    [2040 Slider bottom.STEP]
2021-03-15 Rename 2040 Slider top.STEP to Step Files/2040 Slider top.STEP
    [2040 Slider top.STEP]
2021-03-15 Rename Bearing Clip Ring.STEP to Step Files/Bearing Clip Ring.STEP
    [Bearing Clip Ring.STEP]
2021-03-15 Rename Bearing Inner Race - 127 x 146.05 x 12.7mm.STEP to Step Files/Bearing Inner Race - 127 x 146.05 x 12.7mm.STEP
    [Bearing Inner Race - 127 x 146.05 x 12.7mm.STEP]
2021-04-12 Rename Tasmanian Launch/Tasmanian.vcxproj.filters to Tasmanian Launch/Code/Tasmanian.vcxproj.filters
2021-04-12 Rename Tasmanian Launch/Code/Tasmanian.vcxproj.filters to Tasmanian_Launch/Code/Tasmanian.vcxproj.filters
2021-04-19 Rename Step Files/Tripod Mount.STEP to Step Files/Dynamic Lighting/Tripod Mount.STEP
    [Tripod Mount.STEP]
2021-04-19 Rename Step Files/Hot Shoe Cap.STEP to Step Files/Focus & Zoom Extension/Hot Shoe Cap.STEP
    [Hot Shoe Cap.STEP]
